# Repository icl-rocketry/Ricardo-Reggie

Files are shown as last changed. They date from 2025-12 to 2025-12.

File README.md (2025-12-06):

# Ricardo Board Template
This is a KiCad template including the required components for an ESP32S3 with a USB-C port, a CAN transceiver, as well as logic power input regulation. This is the bare minimum needed for boards in the ricardo ecosystem. If you have followed the [hardware library usage instructions](https://github.com/icl-rocketry/iclr-hw), the hardware libraries will automatically be added to every project started from this template.

## Usage
To use this, clone this repository in your KiCad user templates folder.

By default, this folder is:

MacOS - ```/Users/{USERNAME}/Documents/KiCad/8.0/template/```

Windows -  ```%USERPROFILE%/Documents/KiCad/8.0/template```

Linux - ```/home/{USERNAME}/.local/share/kicad/8.0/template```

Then, you will be able to access the template when making a new project in ```KiCad -> File -> New Project from Template... -> User Templates```

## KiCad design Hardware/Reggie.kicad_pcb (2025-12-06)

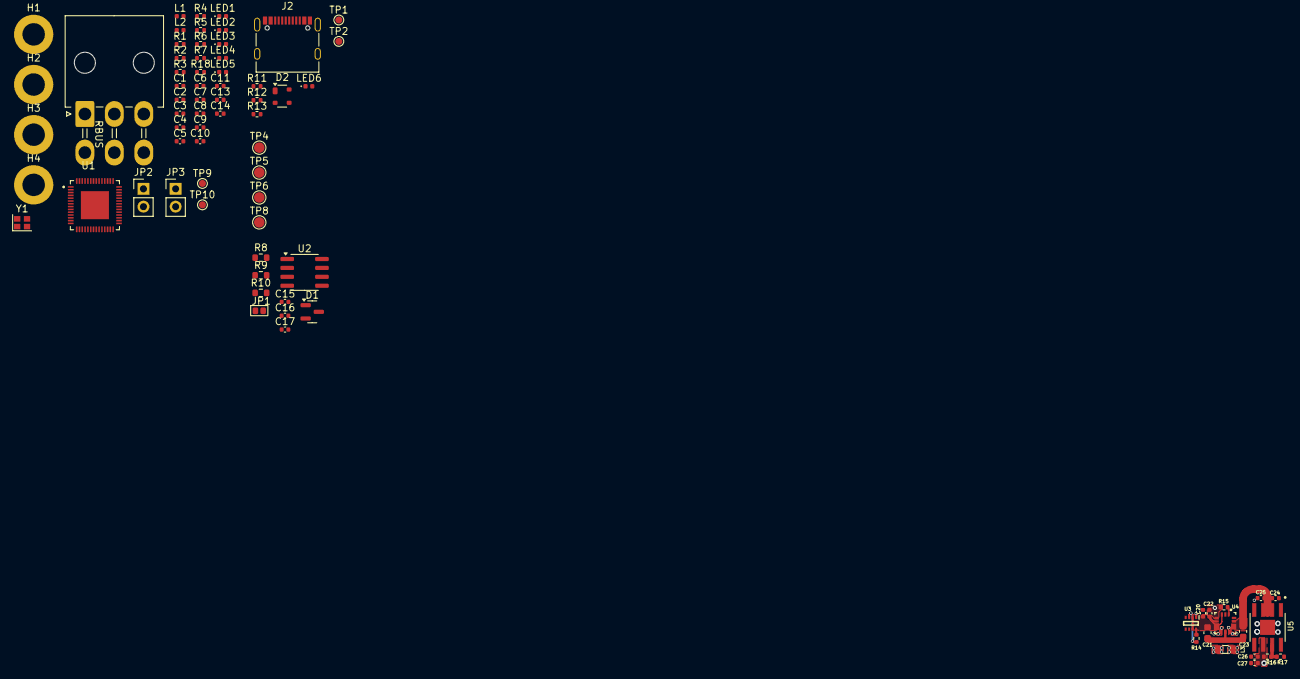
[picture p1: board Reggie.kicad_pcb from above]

Board: 4 copper layers, 76 parts (0 on the bottom side), 38 nets.

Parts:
C1, C16, C20, C24, C26: 10uF; C_0402_1005Metric
C2, C4, C7, C22: 1uF; C_0402_1005Metric
C3, C5, C6, C8, C10, C11, C27: 0.1uF; C_0402_1005Metric
C9: 10nF; C_0402_1005Metric
C13, C14: 11pF; C_0402_1005Metric
C15: 100nF; C_0402_1005Metric
C17: 47nF; C_0402_1005Metric
C21: 10uF; C_0603_1608Metric
C23: 22uF; C_0603_1608Metric
C25: 4.7uF; C_0402_1005Metric
D1: SM712_SOT23; SOT-23
D2: SP0503BAHT; SOT-143
H1, H2, H3, H4: MountingHole_Pad; MountingHole_3.2mm_M3_DIN965_Pad
J1: RBUS; Molex_Mini-Fit_Jr_5569-06A2_2x03_P4.20mm_Horizontal
J2: USB_C_Receptacle_USB2.0; USB_C_Receptacle_Palconn_UTC16-G
JP1: TermJP; SmallerSolderJP
JP2, JP3: Conn_01x02_Male; PinHeader_1x02_P2.54mm_Vertical
L1: 2.0nH; L_0402_1005Metric
L2: 20nH; L_0402_1005Metric
L3: 1uH; L_0805_2012Metric
LED1, LED2: GREEN_LED; LED_0402_1005Metric
LED3: ORANGE_LED; LED_0402_1005Metric
LED4: BLUE_LED; LED_0402_1005Metric
LED5: RED_LED; LED_0402_1005Metric
LED6: WHITE_LED; LED_0402_1005Metric
R1, R3: 10K; R_0402_1005Metric
R2, R4: 470; R_0402_1005Metric
R5, R18: 1k; R_0402_1005Metric
R6: 499R; R_0402_1005Metric
R7: 3k; R_0402_1005Metric
R8: 0; R_0603_1608Metric
R9, R10: 60; R_0603_1608Metric
R11, R12, R13: 5.1k; R_0402_1005Metric
R14, R17: 10k; R_0402_1005Metric
R15: 14k; R_0402_1005Metric
R16: 56k; R_0402_1005Metric
TP1, TP2, TP9, TP10: TestPoint; TestPoint_Pad_D1.0mm
TP4, TP5, TP6, TP8: TestPoint; TestPoint_Pad_D1.5mm
U1: ESP32-S3; QFN40P700X700X90-57N
U2: SN65HVD230; SOIC-8_3.9x4.9mm_P1.27mm
U3: LM66200DRLR; SOTFL50P160X60-8N
U4: MAX77827AEFD+T; CONV_MAX77827AEFD+T
U5: SC4215ASTRT; SOIC127P599X175-9N
Y1: R940000171; Crystal_SMD_2016-4Pin_2.0x1.6mm

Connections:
+3V3: C1.1, C4.1, C5.1, C7.1, C9.1, C10.1, C11.1, C15.1, C16.1, C26.2, C27.2, L1.1, R1.1, R2.1, R3.1, R4.2, R5.1, R16.1, R18.1, TP6.1, U1.20 (VDD3P3_RTC), U1.46 (VDD3P3_CPU), U1.55 (VDDA), U1.56 (VDDA), U2.3 (VCC), U5.6 (VOUT)
/BOOT: C8.1, JP3.1, R3.2, U1.5 (GPIO0/BOOT)
/CAN+: D1.2 (A2), J1.5, R9.1, U2.7 (CANH)
/CAN-: D1.1 (A1), J1.6, R10.2, U2.6 (CANL)
/CAN-BUS/Vref: JP1.1 (A), U2.5 (Vref)
/CAN_RX: LED3.1 (K), U2.4 (R)
/CAN_TX: LED2.1 (K), U2.1 (D)
/CHIP_PU: C2.1, C3.1, JP2.1, R1.2, U1.4 (CHIP_PU/RESET)
/Data+: D2.4 (K), J2.A6 (D+), J2.B6 (D+), TP2.1, U1.26 (GPIO20/USB_D+/ADC2_CH9)
/Data-: D2.3 (K), J2.A7 (D-), J2.B7 (D-), TP1.1, U1.25 (GPIO19/USB_D-/ADC2_CH8)
/Power/BBIN: C20.1, C21.1, TP4.1, U3.2 (VOUT_1), U3.7 (VOUT_2), U4.3 (EN), U4.6 (IN)
/Power/BBOUT: C23.1, C24.1, C25.1, TP8.1, U4.11 (OUT), U4.13 (OUTS), U5.2 (EN), U5.3 (VIN)
/Power/BIAS: C22.1, U4.5 (BIAS)
/Power/FBIn: R16.2, R17.1, U5.7 (ADJ)
/Power/LX1: L3.1, U4.8 (LX1)
/Power/LX2: L3.2, U4.10 (LX2)
/Power/SEL: R15.1, U4.1 (SEL)
/RXD: TP10.1, U1.50 (U0RXD/PROG/GPIO44)
/TXD: LED1.1 (K), R6.1, TP9.1
GND: C1.2, C2.2, C3.2, C4.2, C5.2, C6.2, C7.2, C8.2, C9.2, C10.2, C11.2, C13.2, C14.2, C15.2, C16.2, C17.2, C20.2, C21.2, C22.2, C23.2, C24.2, C25.2, C26.1, C27.1, D1.3 (common), D2.1 (A), H1.1, H2.1, H3.1, H4.1, J1.1, J1.2, J2.A1 (GND), J2.A12 (GND), J2.B1 (GND), J2.B12 (GND), J2.S1 (SHIELD), JP2.2, JP3.2, LED4.1 (K), LED5.1 (K), LED6.1 (K), R8.2, R11.2, R12.1, R15.2, R17.2, U1.57 (GND), U2.2 (GND), U3.1 (GND_1), U3.4 (~ON), U3.5 (GND_2), U4.4 (AGND), U4.9 (PGND), U5.8 (GND), U5.9 (GND), Y1.2, Y1.4
unnamed: C6.1, L1.2, U1.2 (VDD3P3), U1.3 (VDD3P3)
unnamed: C14.1, L2.2, Y1.1
unnamed: J2.A5 (CC1), R11.1
unnamed: J2.B5 (CC2), R12.2
unnamed: C17.1, JP1.2 (B), R9.2, R10.1
unnamed: LED1.2 (A), R2.2
unnamed: LED2.2 (A), R5.2
unnamed: LED3.2 (A), R18.2
unnamed: LED4.2 (A), R4.1
unnamed: LED5.2 (A), R7.2
unnamed: LED6.2 (A), R13.2
unnamed: R6.2, U1.49 (U0TXD/PROG/GPIO43)
unnamed: C13.1, U1.53 (XTAL_N), Y1.3
unnamed: L2.1, U1.54 (XTAL_P)
unnamed: R8.1, U2.8 (Rs)
unnamed: R14.2, U3.8 (ST)
RBUS_uC_V: J1.3, TP5.1, U3.6 (VIN2)
VBUS: D2.2 (K), J2.A4 (VBUS), J2.A9 (VBUS), J2.B4 (VBUS), J2.B9 (VBUS), R13.1, R14.1, U3.3 (VIN1)

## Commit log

2025-12-06 Updated TVS diode
    [pressure.kicad_sch, servo.kicad_sch]
2025-12-09 refactored files, get to fully review
    [Reggie.kicad_pcb, Reggie.kicad_sch, buck.kicad_sch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]
2025-12-16 tvs diode updated
    [Reggie.kicad_sch, servo.kicad_sch]
